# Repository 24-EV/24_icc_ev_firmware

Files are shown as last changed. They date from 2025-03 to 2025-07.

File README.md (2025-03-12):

# 24 INHA EV 데이터 로깅 앱 사용법  

### 완성도를 높이기 위하여 조금씩 수정 예정입니다. 업데이트 날짜 확인하여 이전의 코드, 방식과의 차이점 파악 후 진행해주세요.

### 깃허브 레포지토리 주소

클라이언트 : https://github.com/nitepp04/24_icc_ev_client

서버 : https://github.com/nitepp04/24_icc_ev_server

펌웨어 : https://github.com/nitepp04/24_icc_ev_firmware

## 주요 기능

- 차량의 컨트롤러 및 모듈에서 오는 데이터 값을 시각화
    - 현재 받는 데이터
        - timestamp
            - Real TIme Clock 모듈
            - 당시 RTC 모듈 고장으로 인하여 서버의 시간으로 대체함
            - 복구 원할 시 서버 코드 수정 필요
        - RPM
        - MOTOR_CURRENT
        - BATTERY_VOLTAGE
        - THROTTLE_SIGNAL
        - CONTROLLER_TEMPERATURE
        - SPEED
            - 클라이언트에선 velocity라는 키값으로 사용됨
        - BATTERY_PERCENT
        - lat, lng
            - GPS 모듈 고장
            - 클라이언트 코드에는 구현되어 있으나, 서버 코드에서 삭제함.
            - 복구 원할 시 서버 코드 수정 필요
- 차량 현재 위치 시각화
    - 카카오맵 API를 통하여 차량의 현재 위치를 시각화한다.
- Excel 데이터 다운로드
    - 원하는 시간대의 데이터를 DB에서 불러와 액셀 파일로 다운로드

## 용어 정리

- JavaScript : 프로그래밍 언어
- React : JavaScript 기반 UI 라이브러리
- Node.js : JavaScript 실행 환경
    - 브라우저에서만 실행 가능했던 JavaScript를 서버에서도 실행 가능하도록 해줌
- Express : Node.js의 프레임워크. Express 는 Node.js 위에서 동작하는 웹 프레임 워크
- AWS EC2 : 아마존에서 빌려주는 컴퓨터
- AWS DynamoDB : NoSQL 데이터베이스
    - 고정된 테이블 구조를 사용하지 않고, 다양한 데이터 구조를 저장할 수 있는 데이터 베이스.
    - JSON 형식 저장 가능
- JSON : 사람도 기계도 읽기 쉬운 경량 데이터 형식.
- Vercel : 프론트엔드 프로젝트 배포 클라우드 플랫폼으로, 깃허브와 연동하여 코드 푸시 때마다 자동 업데이트.
- Git : 버전 관리 시스템
- GitHub : Git을 온라인에서 저장하고 협업할 수 있는 플랫폼.
    - 코드를 수정할 때마다 git에 업데이트 하거나, 예전 코드로 다시 돌아갈 수 있고, 이를 github에 올려 온라인으로 저장하고 협업할 수 있습니다.
- 터미널 명령어(CLI) : 터미널에서 사용하는 명령어
    - 이제 등장할 cd, chmod, ls 등이 있다.

프로그램 개선을 원할 때, 어떠한 용어가 있는지 알면 도움이 될 거라 생각하여 검색하기 난감할 것 같은 용어들 몇개만 짧게 적어둡니다.

## 설치 및 실행 방법

### 기본 설정

1. AWS 계정 생성 : https://deoking.tistory.com/27
    1. aws.amazon.com/ko/
    2. 관리 잘 하셔야 돼요. 안 그러면 비용 폭탄 맞아요
2. GitHub 계정 생성
    1. github.com
3. VS 코드 설치 및 환경 설정
    1. Visual Studio Code 검색하여 인스톨
    2. 쭉쭉 넘기다가 추가 작업 선택에서 다음과 같이 체크 (권장)
        
        
        
    4. VS 코드를 열어 왼쪽 메뉴바의 Extension → Korean 검색하여 Korean Language Pack for Visual 인스톨
4. 프론트엔드, 백엔드 레포지토리 포크
    1. 현재 문서 상단에 기재되어 있는 프론트엔드, 백엔드의 깃허브 레포지토리 링크로 각각 접속 → 우측 상단의 Fork 버튼 클릭
        
        
        
    2. Owner : 자신 계정, Repository name : 원하는 대로
        
        
        
    3. 자신의 깃허브 레포지토리에 포크된 레포지토리가 잘 생성되었나 체크
    
---

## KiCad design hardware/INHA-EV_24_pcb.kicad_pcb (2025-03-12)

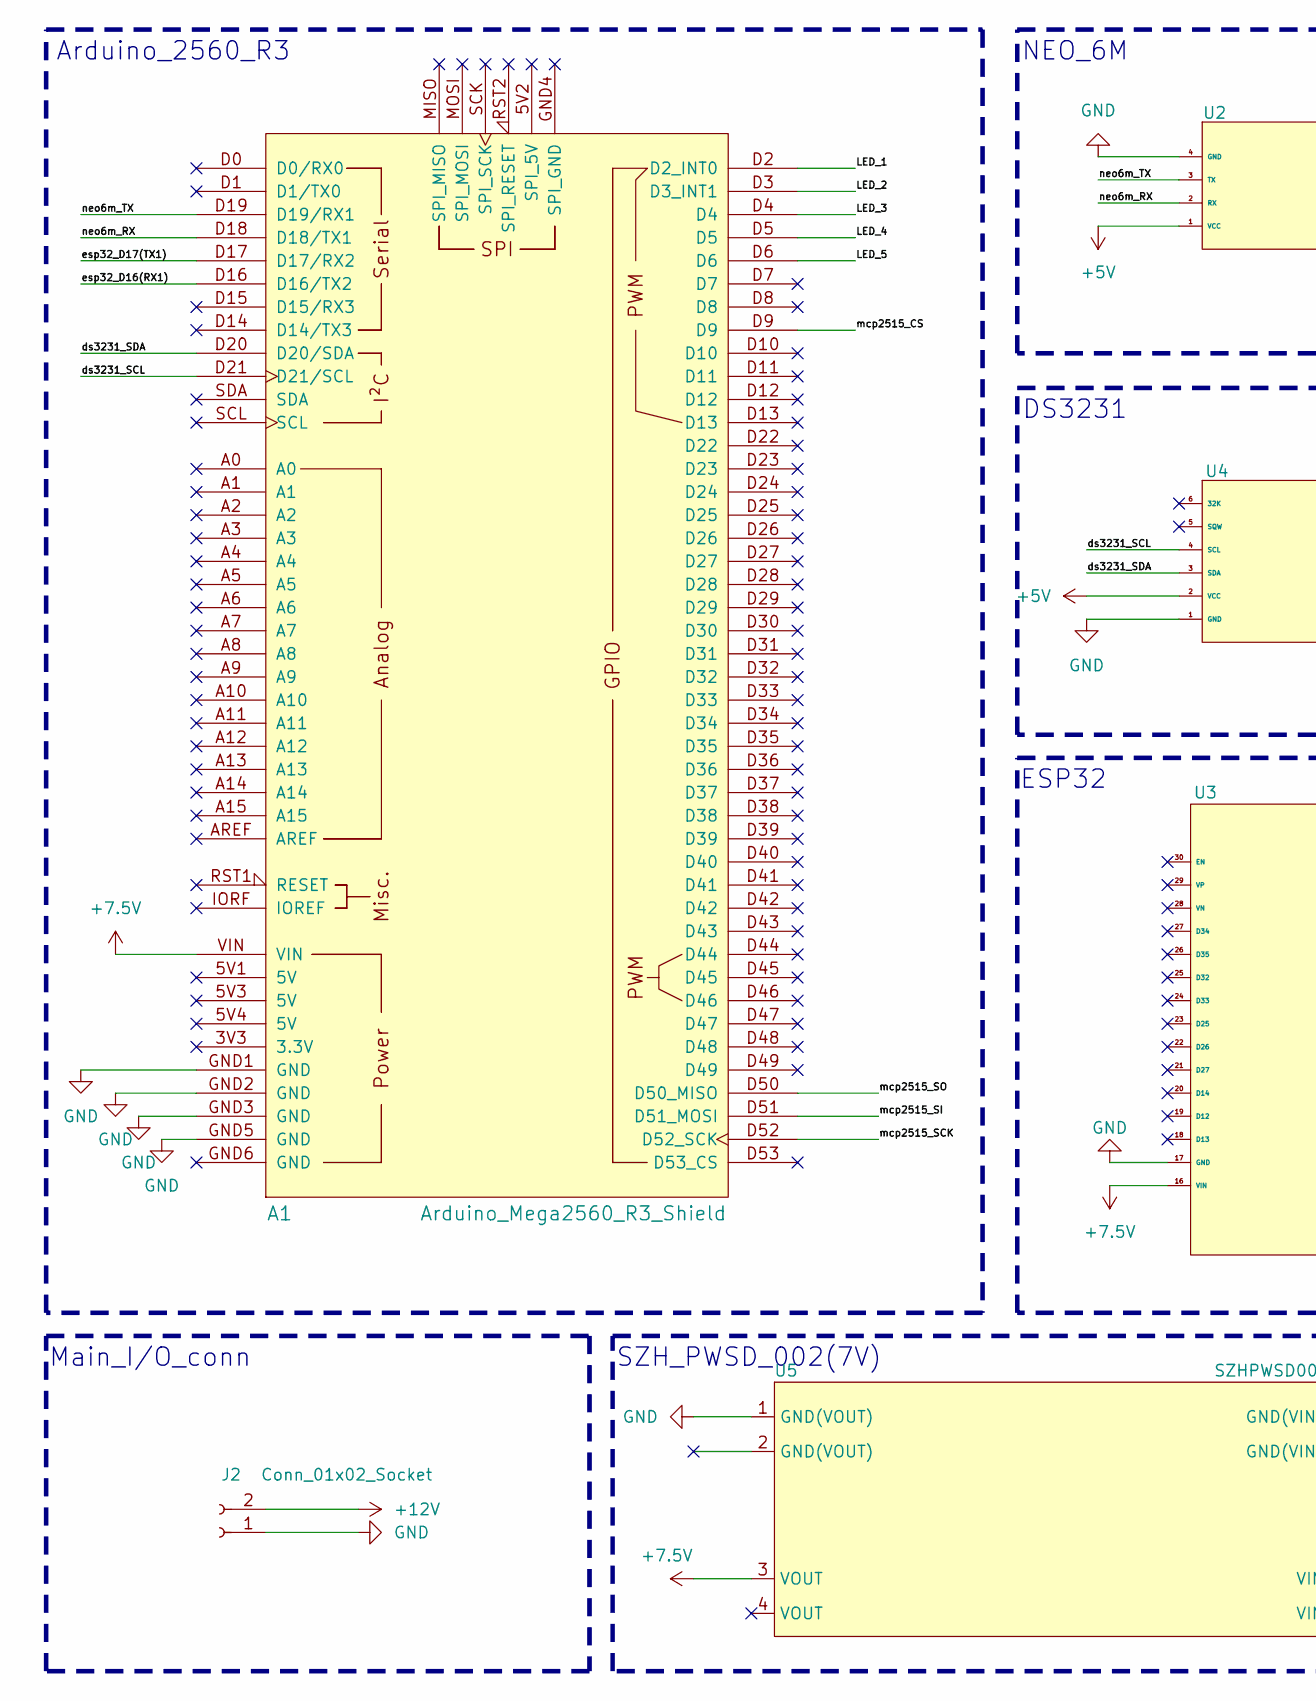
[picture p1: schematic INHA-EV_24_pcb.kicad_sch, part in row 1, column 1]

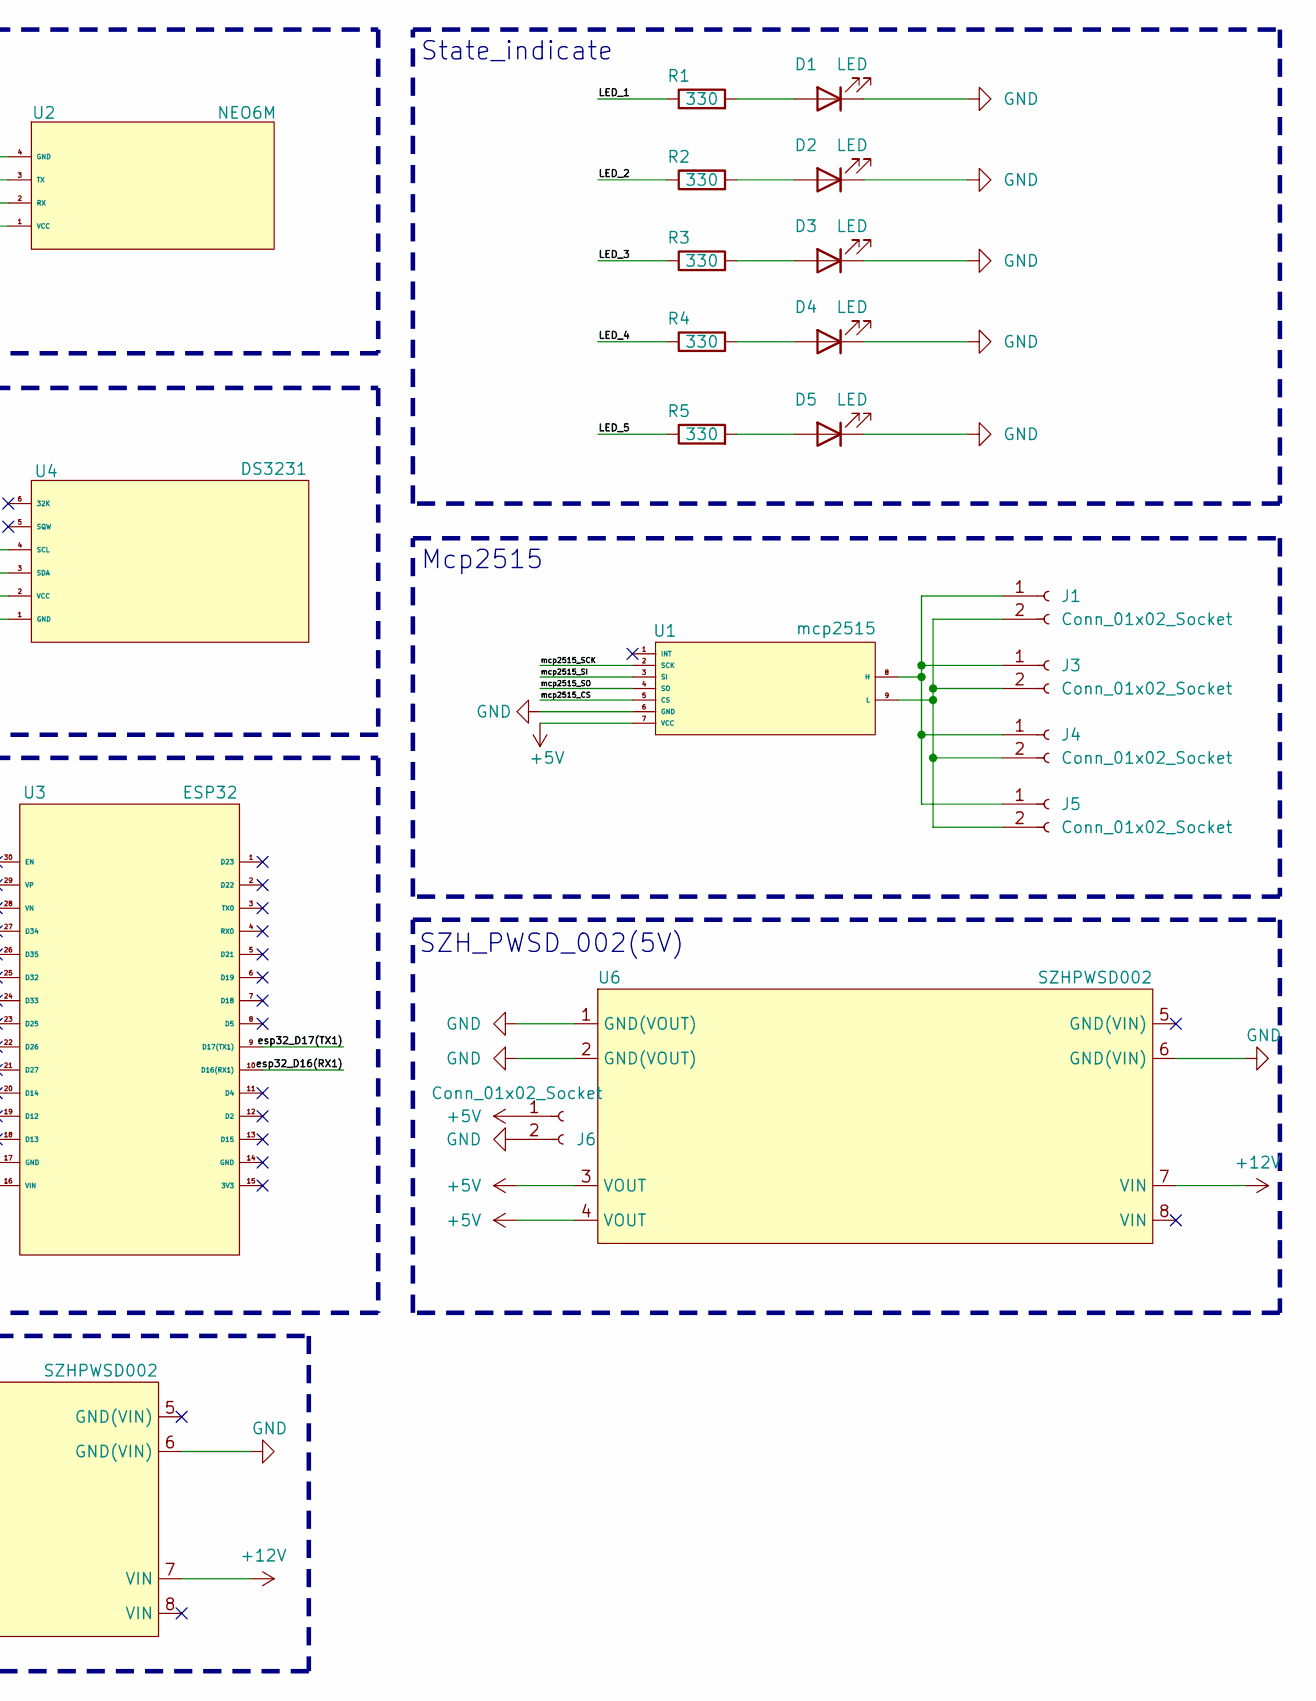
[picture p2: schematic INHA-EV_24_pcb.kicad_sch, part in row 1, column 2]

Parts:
A1: Arduino_Mega2560_R3_Shield
D1, D2, D3, D4, D5: LED; LED_D5.0mm_FlatTop
J1, J2, J3, J4, J5, J6: Conn_01x02_Socket; Molex_KK-254_AE-6410-02A_1x02_P2.54mm_Vertical
R1, R2, R3, R4, R5: 330; R_Axial_DIN0207_L6.3mm_D2.5mm_P10.16mm_Horizontal
U1: mcp2515
U2: NEO6M
U3: ESP32
U4: DS3231
U5, U6: SZHPWSD002; SZHPWSD003

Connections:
+5V: J6.1, U1.7 (VCC), U2.1 (VCC), U4.2 (VCC), U6.3 (VOUT), U6.4 (VOUT)
+7.5V: A1.VIN, U3.16 (VIN), U5.3 (VOUT)
+12V: J2.2, U5.7 (VIN), U6.7 (VIN)
/LED_1: A1.D2 (D2_INT0), R1.1
/LED_2: A1.D3 (D3_INT1), R2.1
/LED_3: A1.D4, R3.1
/LED_4: A1.D5, R4.1
/LED_5: A1.D6, R5.1
/ds3231_SCL: A1.D21 (D21/SCL), U4.4 (SCL)
/ds3231_SDA: A1.D20 (D20/SDA), U4.3 (SDA)
/esp32_D16(RX1): A1.D16 (D16/TX2), U3.10 (D16(RX1))
/esp32_D17(TX1): A1.D17 (D17/RX2), U3.9 (D17(TX1))
/mcp2515_CS: A1.D9, U1.5 (CS)
/mcp2515_SCK: A1.D52 (D52_SCK), U1.2 (SCK)
/mcp2515_SI: A1.D51 (D51_MOSI), U1.3 (SI)
/mcp2515_SO: A1.D50 (D50_MISO), U1.4 (SO)
/neo6m_RX: A1.D18 (D18/TX1), U2.2 (RX)
/neo6m_TX: A1.D19 (D19/RX1), U2.3 (TX)
GND: A1.GND1 (GND), A1.GND2 (GND), A1.GND3 (GND), A1.GND5 (GND), D1.1 (K), D2.1 (K), D3.1 (K), D4.1 (K), D5.1 (K), J2.1, J6.2, U1.6 (GND), U2.4 (GND), U3.17 (GND), U4.1 (GND), U5.1 (GND(VOUT)), U5.6 (GND(VIN)), U6.1 (GND(VOUT)), U6.2 (GND(VOUT)), U6.6 (GND(VIN))
unnamed: D1.2 (A), R1.2
unnamed: D2.2 (A), R2.2
unnamed: D3.2 (A), R3.2
unnamed: D4.2 (A), R4.2
unnamed: D5.2 (A), R5.2
unnamed: J1.1, J3.1, J4.1, J5.1, U1.8 (H)
unnamed: J1.2, J3.2, J4.2, J5.2, U1.9 (L)

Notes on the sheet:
SZH_PWSD_002(5V)
Main_I/O_conn
SZH_PWSD_002(7V)
ESP32
Mcp2515
DS3231
Arduino_2560_R3
NEO_6M
State_indicate

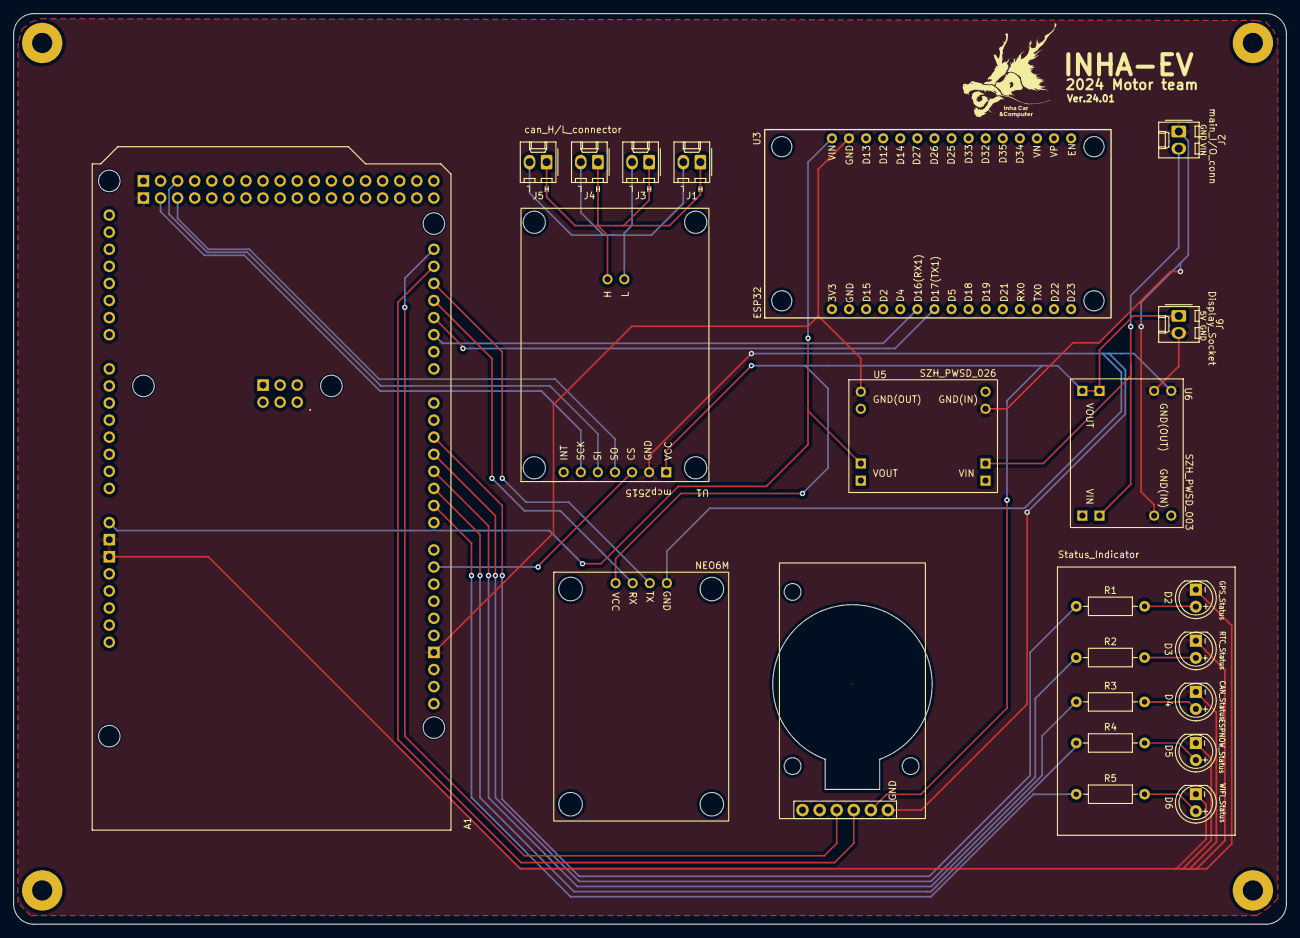
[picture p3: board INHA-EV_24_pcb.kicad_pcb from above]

Board: 2 copper layers, 189.2 x 135.4 mm, 23 parts (1 on the bottom side), 26 nets.

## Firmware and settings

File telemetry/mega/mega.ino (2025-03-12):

#include <SPI.h>
#include <mcp_canbus.h>
#include "RTClib.h"

#define SPI_CS_PIN 9
MCP_CAN CAN(SPI_CS_PIN);  // Set CS pin

RTC_DS3231 rtc;
char daysOfTheWeek[7][12] = { "Sunday", "Monday", "Tuesday", "Wednesday", "Thursday", "Friday", "Saturday" };

// 변수 구조체 설정
struct SensorData {
  int RPM;
  int MOTOR_CUR;
  int BATT_PERCENT;
  int THROTTLE_SIG;
  int CTRL_TEMP;
  int SPEED;
  int BATT_VOLT;
};
SensorData data;

// 상수 설정
float wheeldiameter = 0.5;  // 휠 직경(m)
//float efficiency = 1.0;       // 효율 (부하가 걸렸을 때 모터 효율은 1로 가정)
float efficiency = 0.863;// * 0.94 * 0.98;  // (무부하의 rpm을 받아왔을 때 = 0.91 * 0.863 * 0.94 * 0.98)
float gear_ratio = 3.75;     // 기어비
float pi = 3.141592653589793; // 파이

// CAN 데이터 수신 상태 변수
bool id_1_received = false;
bool id_2_received = false;
unsigned long last_id_1_can_time = 0;  // 마지막으로 받은 ID 1의 CAN 메시지 시간
unsigned long last_id_2_can_time = 0;  // 마지막으로 받은 ID 2의 CAN 메시지 시간

const unsigned long message_delay = 100;  // 동일 ID 처리 간격

void setup() {
  Serial.begin(115200);   // 시리얼 모니터를 위한 시리얼 초기화
  Serial2.begin(115200);  // ESP32와의 UART 통신을 위한 시리얼 초기화

  while (!Serial) {
    ;  // 시리얼 포트 연결을 기다림
  }
  Serial.println("Serial communication initialized.");

  // CAN 버스 초기화
  if (CAN_OK == CAN.begin(CAN_500KBPS)) {
    Serial.println("CAN BUS OK!");
  } else {
    Serial.println("CAN BUS FAIL! Check wiring and connections.");
    while (1);
  }
}

void loop() {
  // CAN 메시지를 수신했는지 확인
  if (CAN_MSGAVAIL == CAN.checkReceive()) {
    unsigned char len = 0;
    unsigned char rxBuf[8];  // CAN으로 받은 데이터를 저장할 버퍼

    CAN.readMsgBuf(&len, rxBuf);  // 데이터를 읽어와 버퍼에 저장
    unsigned long canId = CAN.getCanId();

    // ID 설정
    unsigned long id_1 = 0x0CF11E05;
    unsigned long id_2 = 0x0CF11F05;

    unsigned long current_time = millis();

    // ID 1 수신 처리
    if (canId == id_1 && current_time - last_id_1_can_time > message_delay) {
      data.RPM = (rxBuf[1] * 256) + rxBuf[0];  // RPM 값 수신

      // 모터 효율과 기어비를 반영하여 RPM을 Powertrain RPM으로 변환
      float rpm_powertrain = data.RPM * (sqrt(efficiency) / gear_ratio);

      // 속도 계산 (m/s)
      float velocity_mps = rpm_powertrain * (2 * pi * (wheeldiameter / 2) / 60);

      // 속도를 km/h로 변환
      data.SPEED = velocity_mps * 3.6;

      // 기타 데이터 처리
      data.MOTOR_CUR = ((rxBuf[3] * 256) + rxBuf[2]) / 10;
      data.BATT_VOLT = ((rxBuf[5] * 256) + rxBuf[4]) / 10;
      data.BATT_PERCENT = map(data.BATT_VOLT * 100, 4700, 5460, 0, 100);
      id_1_received = true;
      last_id_1_can_time = current_time;
    }
    // ID 2 수신 처리
    else if (canId == id_2 && current_time - last_id_2_can_time > message_delay) {
      data.THROTTLE_SIG = rxBuf[0];
      data.CTRL_TEMP = rxBuf[1] - 40;
      id_2_received = true;
      last_id_2_can_time = current_time;
    }
  }

  // ID 1과 ID 2가 모두 수신된 경우에만 데이터를 전송
  if (id_1_received && id_2_received) {
    sendDataToESP32();
    // 상태 초기화
    id_1_received = false;
    id_2_received = false;
  }

  delay(100);
}

void sendDataToESP32() {
  Serial.println("Sending data to ESP32...");

  // 데이터 전송 전 디버깅을 위해 구조체 멤버들을 개별적으로 출력
  Serial.print("RPM: ");
  Serial.println(data.RPM);
  Serial.print("MOTOR_CUR: ");
  Serial.println(data.MOTOR_CUR);
  Serial.print("BATT_VOLT: ");
  Serial.println(data.BATT_VOLT);
  Serial.print("THROTTLE_SIG: ");
  Serial.println(data.THROTTLE_SIG);
  Serial.print("CTRL_TEMP: ");
  Serial.println(data.CTRL_TEMP);
  Serial.print("SPEED (km/h): ");
  Serial.println(data.SPEED);  // km/h 단위로 속도를 출력
  Serial.print("BATT_PERCENT: ");
  Serial.println(data.BATT_PERCENT);

  // ESP32로 데이터 전송
  Serial2.write((uint8_t*)&data, sizeof(data));

  Serial.println("Data sent to ESP32");
  Serial.println("-----------------------------");
  Serial.println();  // 줄바꿈
}

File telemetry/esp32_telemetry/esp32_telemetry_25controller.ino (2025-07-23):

// 25년도 컨트롤러에 맞게 코드 수정함.
// 기존은 24년도 컨트롤러 코드. esp32 모듈이 없어서 정상 작동하는지 테스트 못 해봤습니다.

#include <WiFi.h>
#include <RingBuf.h>
#include <ArduinoJson.h>
#include <SocketIOclient.h>

// SON_ID
#define SON_ID "nitepp04"
#define SON_PWD "00000000"

// MY_ID
#define MY_ID "kimchunsick"
#define MY_PWD "01234567890"

// Hotspot AP configurations
const char ssid[] = MY_ID;
const char password[] = MY_PWD;

// 서버 정보
const char server[] = "43.203.166.209"; // 소켓IO 서버 IP
const char url[] = "/socket.io/?EIO=4"; // 소켓IO 서버 URL
const int port = 2004;                  // 소켓IO 서버 포트

char log_payload[512]; // JSON 메시지를 저장할 버퍼

SocketIOclient socketIO;
RingBuf<char, 1024> tx_buf;

unsigned long lastReceiveTime = 0;
const unsigned long timeoutDuration = 100;

char buffer[44]; // 44바이트 수신 버퍼
int bufferIndex = 0;
bool server_conn = false;

void setup()
{
    Serial.begin(115200);
    Serial2.begin(115200, SERIAL_8N1, 16, 17);
    Serial.println("Serial2 initialized.");

    WiFi.mode(WIFI_STA);
    WiFi.begin(ssid, password);

    while (WiFi.status() != WL_CONNECTED)
    {
        delay(500);
        Serial.print(".");
    }
    Serial.println("\nWi-Fi 연결 완료");

    socketIO.begin(server, port, url);
    socketIO.onEvent(socketIOEvent);
    Serial.println("Socket.IO 연결 시도 중...");
}

void loop()
{
    if (WiFi.status() != WL_CONNECTED)
    {
        Serial.println("Wi-Fi 연결 끊김, 재연결 시도 중...");
        WiFi.reconnect();
        delay(500);
        return;
    }

    socketIO.loop();

    if (Serial2.available() > 0)
    {
        unsigned long currentTime = millis();

        if (lastReceiveTime == 0)
        {
            lastReceiveTime = currentTime;
        }

        while (Serial2.available() > 0 && currentTime - lastReceiveTime < timeoutDuration)
        {
            char received = Serial2.read();
            buffer[bufferIndex++] = received;

            if (bufferIndex == 44)
            {
                processReceivedData();
                bufferIndex = 0;
                lastReceiveTime = 0;
                break;
            }

            currentTime = millis();
        }

        if (currentTime - lastReceiveTime >= timeoutDuration)
        {
            Serial.println("Timeout occurred, discarding data.");
            bufferIndex = 0;
            lastReceiveTime = 0;
        }
    }
}

void processReceivedData()
{
    for (int x = 0; x < 44; x++)
    {
        tx_buf.lockedPushOverwrite(buffer[x]);
    }

    if (!tx_buf.isEmpty())
    {
        char pop;
        char buf[44];

        for (int x = 0; x < 44; x++)
        {
            if (tx_buf.lockedPop(pop))
            {
                buf[x] = pop;
            }
            else
            {
                Serial.print("[empty]");
                break;
            }
        }

// 2바이트씩 병합 (Little Endian 기준)
#define GET_16BIT(i) ((uint16_t)((uint8_t)buf[i] | ((uint8_t)buf[i + 1] << 8)))

        uint16_t motor_temp_L = GET_16BIT(0);
        uint16_t controller_temp_L = GET_16BIT(2);
        uint16_t current_L = GET_16BIT(4);
        uint16_t voltage_L = GET_16BIT(6);
        uint16_t power_L = GET_16BIT(8);
        uint16_t rpm_L = GET_16BIT(10);
        uint16_t torque_L = GET_16BIT(12);
        uint16_t torque_cmd_L = GET_16BIT(14);

        uint16_t motor_temp_R = GET_16BIT(16);
        uint16_t controller_temp_R = GET_16BIT(18);
        uint16_t current_R = GET_16BIT(20);
        uint16_t voltage_R = GET_16BIT(22);
        uint16_t power_R = GET_16BIT(24);
        uint16_t rpm_R = GET_16BIT(26);
        uint16_t torque_R = GET_16BIT(28);
        uint16_t torque_cmd_R = GET_16BIT(30);

        uint16_t adc_signal = GET_16BIT(32);
        uint16_t speed = GET_16BIT(34);
        uint16_t yaw_rate = GET_16BIT(36);
        uint16_t steering_angle = GET_16BIT(38);
        uint16_t batt_percent = GET_16BIT(40);
        uint16_t total_power = GET_16BIT(42);

        // JSON 메시지 생성
        snprintf(log_payload, sizeof(log_payload),
                 "[\"tlog\", {"
                 "\"Motor_temp_L\":%u, \"Controller_temp_L\":%u, \"Current_L\":%u, \"Voltage_L\":%u, \"Power_L\":%u, \"RPM_L\":%u, \"Torque_L\":%u, \"Torque_cmd_L\":%u, "
                 "\"Motor_temp_R\":%u, \"Controller_temp_R\":%u, \"Current_R\":%u, \"Voltage_R\":%u, \"Power_R\":%u, \"RPM_R\":%u, \"Torque_R\":%u, \"Torque_cmd_R\":%u, "
                 "\"ADC_Signal\":%u, \"Speed\":%u, \"Yaw_rate\":%u, \"Steering_angle\":%u, \"Batt_percent\":%u, \"Total_power\":%u"
                 "}]",
                 motor_temp_L, controller_temp_L, current_L, voltage_L, power_L, rpm_L, torque_L, torque_cmd_L,
                 motor_temp_R, controller_temp_R, current_R, voltage_R, power_R, rpm_R, torque_R, torque_cmd_R,
                 adc_signal, speed, yaw_rate, steering_angle, batt_percent, total_power);

        if (server_conn)
        {
            socketIO.sendEVENT(log_payload);
            Serial.print("메시지 전송 완료: ");
            Serial.println(log_payload);
        }
    }
}

void socketIOEvent(socketIOmessageType_t type, uint8_t *payload, size_t length)
{
    switch (type)
    {
    case sIOtype_CONNECT:
        Serial.println("Socket.IO 연결 성공");
        server_conn = true;
        socketIO.send(sIOtype_CONNECT, "/");
        break;

    case sIOtype_DISCONNECT:
        Serial.println("Socket.IO 연결 해제");
        server_conn = false;
        break;

    case sIOtype_EVENT:
        Serial.print("이벤트 수신: ");
        Serial.println((char *)payload);
        break;

    case sIOtype_ERROR:
        Serial.println("Socket.IO 오류 발생");
        break;

    default:
        break;
    }
}

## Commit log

2025-03-12 fix: pcb foldering
    [INHA-EV_24_pcb.kicad_pcb, INHA-EV_24_pcb.kicad_sch]
2025-03-12 docs : README.md 업데이트
2025-07-23 feat : 25년도 새 컨트롤러에 맞는 데이터 버퍼 처리
    25년도 컨트롤러는 기존과 다른 방식의 데이터 값을 주기에 거기에 맞는 데이터 버퍼를 처리하도록 코드를 수정함.
    코드 작성 시에 테스트 진행 환경이 갖추어지지 않았기에, 정상작동하는지는 모름 ..
    [esp32_telemetry_25controller.ino]
